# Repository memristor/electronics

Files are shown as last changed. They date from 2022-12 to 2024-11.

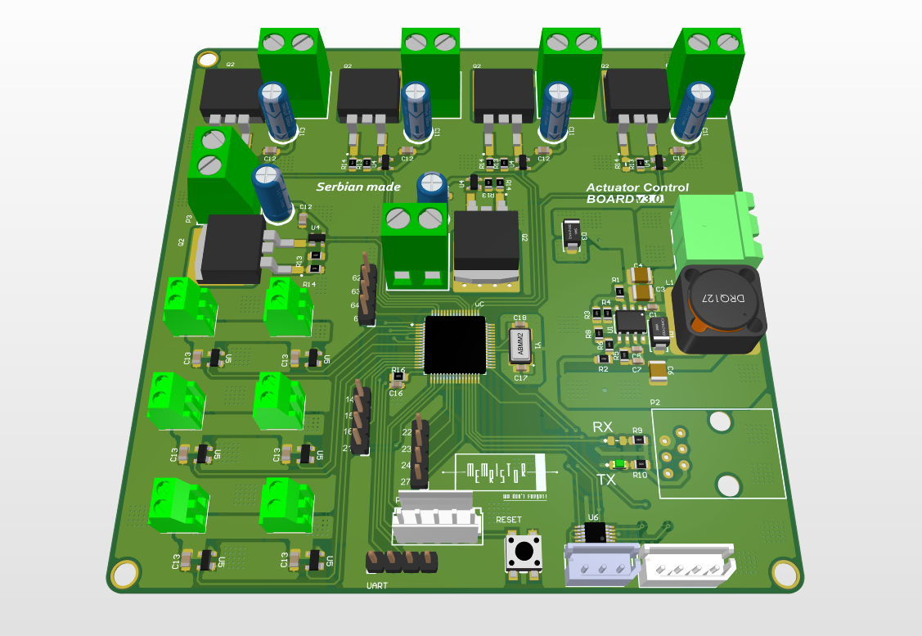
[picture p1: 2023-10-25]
actuator_board/PCB_3D.png

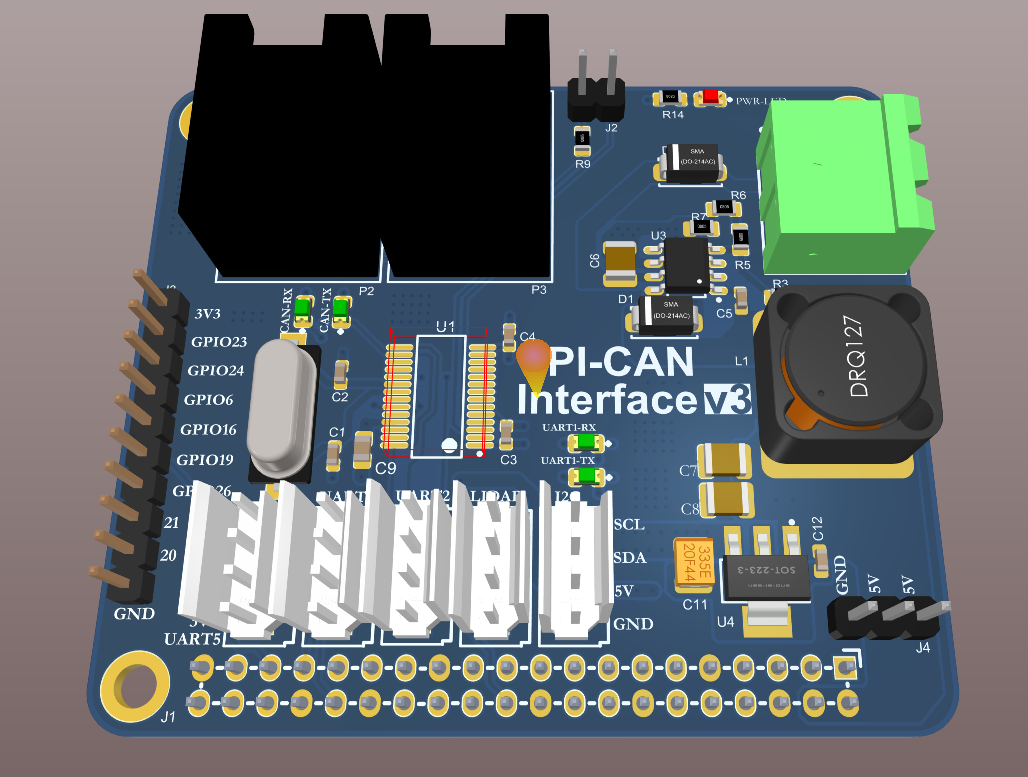
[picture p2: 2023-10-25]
pi_can_board/PCB_3D.png

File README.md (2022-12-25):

# electronics
PCBs in our Robots

Here is how we design our folder structure:

`project_name/`\
|&nbsp;&nbsp;&nbsp;&nbsp;`output_job/`\
|&nbsp;&nbsp;&nbsp;&nbsp;`pcb/`\
|&nbsp;&nbsp;&nbsp;&nbsp;`schematic/`\
|&nbsp;&nbsp;&nbsp;&nbsp;`project_name.PrjPcb`
  
Everything should be snake_case.

Gitignore considerations:\
https://electronics.stackexchange.com/questions/159220/which-files-to-version-control-for-an-altium-pcb-project
https://www.allspice.io/post/git-for-altium

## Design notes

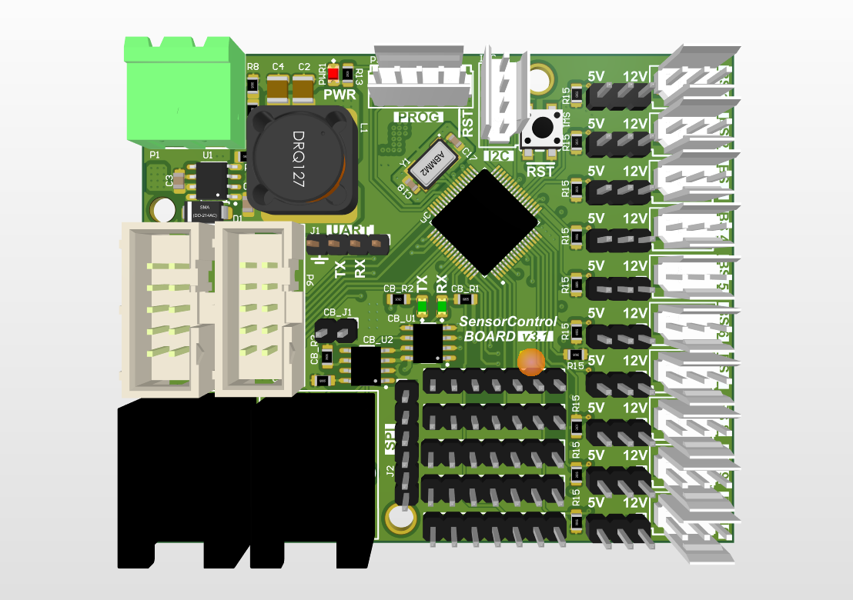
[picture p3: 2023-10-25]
sensor_board/PCB_3D.png

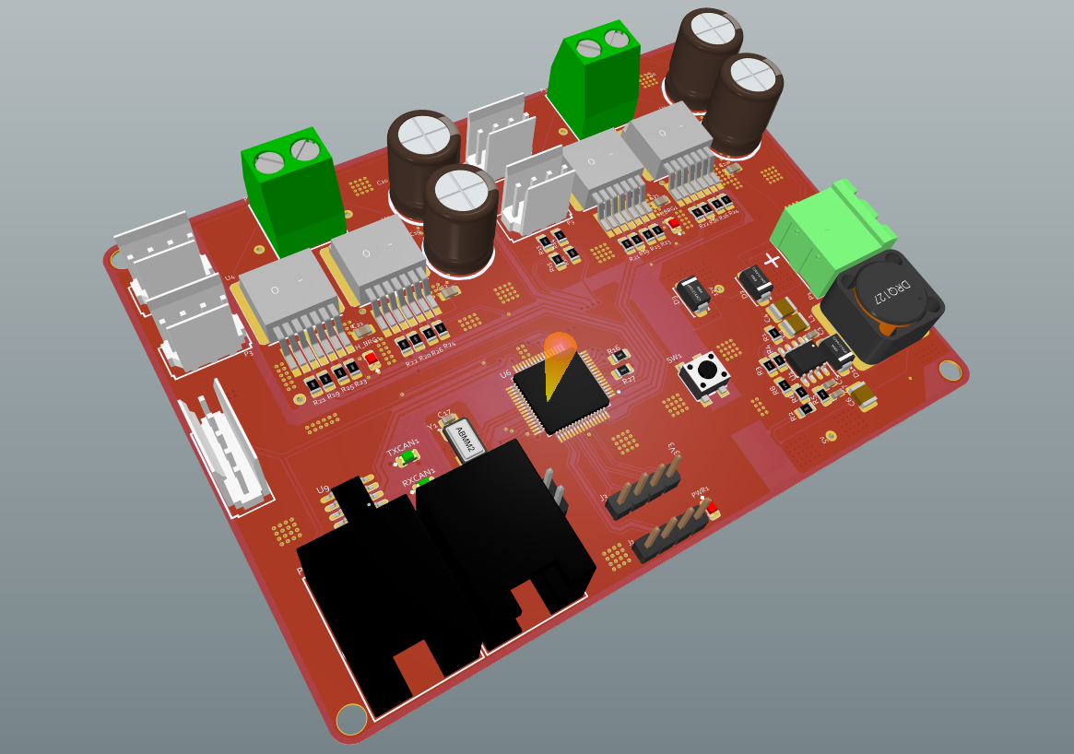
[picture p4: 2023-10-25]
motion_board/PCB_3D.png

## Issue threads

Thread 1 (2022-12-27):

Pi CAN board v3 review

VladimirVincan, 2022-12-27:
Referenca za Raspberry Pi 4: [datasheet](https://datasheets.raspberrypi.com/rpi4/raspberry-pi-4-datasheet.pdf)
Referenca za MCP251863: [datasheet](https://ww1.microchip.com/downloads/aemDocuments/documents/APID/ProductDocuments/DataSheets/MCP251863-Data-Sheet-DS20006624A.pdf)
Referenca za TPS5430: [datasheet](https://www.ti.com/lit/ds/symlink/tps5430.pdf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)

**Analiza Raspberry pinout-a:**
Potencijalno si mogao ukloniti LM2937-5, ako dovedeš Rasberiju 5 V, pretpostavljam da će vratiti 3.3 V.
Zašto nisi povezao sve GPIO pinove sa Rasberija na prilagodnu? Mislim na pinove 11, 12, 13, 15 i 26.
- pinovi 8 i 10 su jasni, RXD i TXD
- pinovi 3 i 5 su jasni, I2C
- pinovi 19, 21 i 23 su jasni, SPI
- koliko sam shvatio, pin 24 je SPI Chip Select 0 pin, i pošto imammo samo jednu periferiju, CS1 nam ne treba.
- pinovi 27 i 28 su I2C interfejs za EEPROM. Piše u datasheet-u: _DO NOT USE these pins for anything other than attaching an I2C ID EEPROM. Leave unconnected if ID EEPROM not required._ Da li tu može biti problema?
- pinovi 7 i 29 imaju ALT4 funkciju UART, jasno
- pinovi 32 i 33 imaju ALT4 funkciju UART, jasno
- pin 22 je GPIO koji si povezao sa MCP251863

**Analiza MCP251863 pinouta:**
Gledam sliku FIGURE 1-2: MCP251863 INTERFACING WITH A 3.3V MICROCONTROLLER

- imaš tri kondenzatora od 0.1 uF, odlično
- sa čime je povezan CLKO? Koliko vidim ni sa čim, onda treba staviti NC?
- zašto nisi stavio otpornike i kondenzator između CANH i CANL kao na slici?

UART:

- povezao si TXD sa TXCAN i RXD sa RXCAN, odlično
- povezao si TX od Rasberija (GPIO0) sa TXCAN od mikrokontrolera, zar ne treba obratno (TX sa RX)?
- povezao si RX od Rasberija (GPIO1) sa RXCAN od mikrokontrolera, zar ne treba obratno (RX sa TX)?

SPI:

- MOSI treba da se poveže sa SDI, odlično
- MISO treba da se poveže sa SDO, odlično
- NCS je povezan, odlično
- clock je povezan, odlično
- da bismo bili u normal modu, STDBY pin mora biti na GND, odlično

Interrupti:
- INT0 reaguje ako se pojavi TX poruka
- INT1 reaguje ako se pojavi RX poruka
- INT reaguje ako se pojavi bilo koja poruka.
- Da li nam je potreban interrupt uopšte? Da li da povežemo sva tri interrupta kao što je predloženo? Svi su aktivni na nuli.

Napajanje:
- The VCC of the CAN FD transceiver is connected to 5V - jasno.
- VDD: 2.7V to 5.5V. Pretpostavljam da si odabrao 3.3 V jer GPIO radi na 3.3 V. Koliko vidim sa šematika, CAN radi na istom naponu.

Oscilator:
-  It is recommended by the CAN FD community to use either a 40 or 20 MHz SYSCLK. Može se frekvencija podeliti sa dva unutar mikrokontrolera. Zašto si odabrao 20 MHz, a ne 40?
- Takođe, kako si odabrao kapacitivnost kondenzatora?

**Analiza za LED panel 16x2**
Koliko sam video sa [ovog ](https://www.electroniclinic.com/raspberry-pi-16x2-lcd-i2c-interfacing-and-python-programming/)sajta, redosled pinova je dobar.

**Analiza za TPS5430**
- za otpornost od 3.24kOhm-a, morate proveriti kolika je tolerancija za otpornost kod dobavljača. Ako koristite standardnu E12 seriju otpornika, onda je greška 10%, što može uticati na rezultujući napon. Kako biste to rešili?
- kapacitivnost treba da bude 220uF, a kod vas je 200uF. Već E3 serija nudi 220uF, zašto to niste stavili?
- ENA: On/off control. Below 0.5 V, the device stops switching. Float the pin to enable. Pretpostavljam da je to dobro.

**PCB dizajn**
- Moja navika je da svi GND pad-ovi budu kockasti, a ostali zaobljeni. Da li to ima smisla tako napraviti? Po meni to olakšava debagovanje i snalaženje na pločici.
- Staviti logo fakulteta, univerziteta i našeg tima?

Ammy076, 2023-01-04:
working well

angstrem98, 2023-01-05:
> Potencijalno si mogao ukloniti LM2937-5, ako dovedeš Rasberiju 5 V, pretpostavljam da će vratiti 3.3 V.

Da, vratiće. Mislim da je to odrađeno još ranije tako da se ne bi opterećivao regulator na samom raspberry-ju.

> Zašto nisi povezao sve GPIO pinove sa Rasberija na prilagodnu? Mislim na pinove 11, 12, 13, 15 i 26.

Zašto je to potrebno? Mislim ni da nema mesta na ploči.

> pinovi 27 i 28 su I2C interfejs za EEPROM. Piše u datasheet-u: DO NOT USE these pins for anything other than attaching an I2C ID EEPROM. Leave unconnected if ID EEPROM not required. Da li tu može biti problema?

Ovo si dobro primetio, promaklo mi je, ranije tu nije nista povezivano. Provericu sa Aleksandrom.

> sa čime je povezan CLKO? Koliko vidim ni sa čim, onda treba staviti NC?

Mislim da treba NC.

> zašto nisi stavio otpornike i kondenzator između CANH i CANL kao na slici?

To o čemu govoriš jeste terminacija "split termination". Mi koristimo standardnu terminaciju sa jednim otpornikom 120R.

> povezao si TX od Rasberija (GPIO0) sa TXCAN od mikrokontrolera, zar ne treba obratno (TX sa RX)?
> povezao si RX od Rasberija (GPIO1) sa RXCAN od mikrokontrolera, zar ne treba obratno (RX sa TX)?

Ovo mi nije najjasnije šta tačno misliš, ali sam primetio da je na prvi konektor za aurt dovođeno rxcan i txcan. Prosledio sam Aleksandru da ispravi.

> Da li nam je potreban interrupt uopšte? Da li da povežemo sva tri interrupta kao što je predloženo? Svi su aktivni na nuli.

Potreban je interapt i INT pin je povezan. Tako radi drajver.

> It is recommended by the CAN FD community to use either a 40 or 20 MHz SYSCLK. Može se frekvencija podeliti sa dva unutar mikrokontrolera. Zašto si odabrao 20 MHz, a ne 40?
> Takođe, kako si odabrao kapacitivnost kondenzatora?

Postoji Family Reference Manual za taj kontroler. Ali možeš samo otvoriti šemu Mikroelektronikine Click pločice i dobiti već proverenu kombinaciju kristala i kondenzatora ;)

> za otpornost od 3.24kOhm-a, morate proveriti kolika je tolerancija za otpornost kod dobavljača. Ako koristite standardnu E12 seriju otpornika, onda je greška 10%, što može uticati na rezultujući napon. Kako biste to rešili?

3k24 se uopšte ne koristi, to ti je samo u datasheet-u. Odabrao sam otpornike koji su lakše nabavljivi. A većina se sad standardno isporučuje sa tolerancijom od 1% tako da nema problema.

> kapacitivnost treba da bude 220uF, a kod vas je 200uF. Već E3 serija nudi 220uF, zašto to niste stavili?

200 uF radi ok, provereno u TI simulatoru i na ploči. Fora je što je potreban izlazni kondenzator sa veoma malom ESR, čak ni tantal ne zadovoljava već treba keramika (ili neki skup specijalni kondenzator). Vezivanje paralelno 2x100 uF keramičkih jeste jeftino i nabavljivo rešenje.

> Moja navika je da svi GND pad-ovi budu kockasti, a ostali zaobljeni. Da li to ima smisla tako napraviti? Po meni to olakšava debagovanje i snalaženje na pločici.

Možda bi moglo, vidi sa Aleksandrom. Meni je svejedno.

> Staviti logo fakulteta, univerziteta i našeg tima?

Vidi sa ostalima, ovo je nezavisno razvijano, možda ne treba?

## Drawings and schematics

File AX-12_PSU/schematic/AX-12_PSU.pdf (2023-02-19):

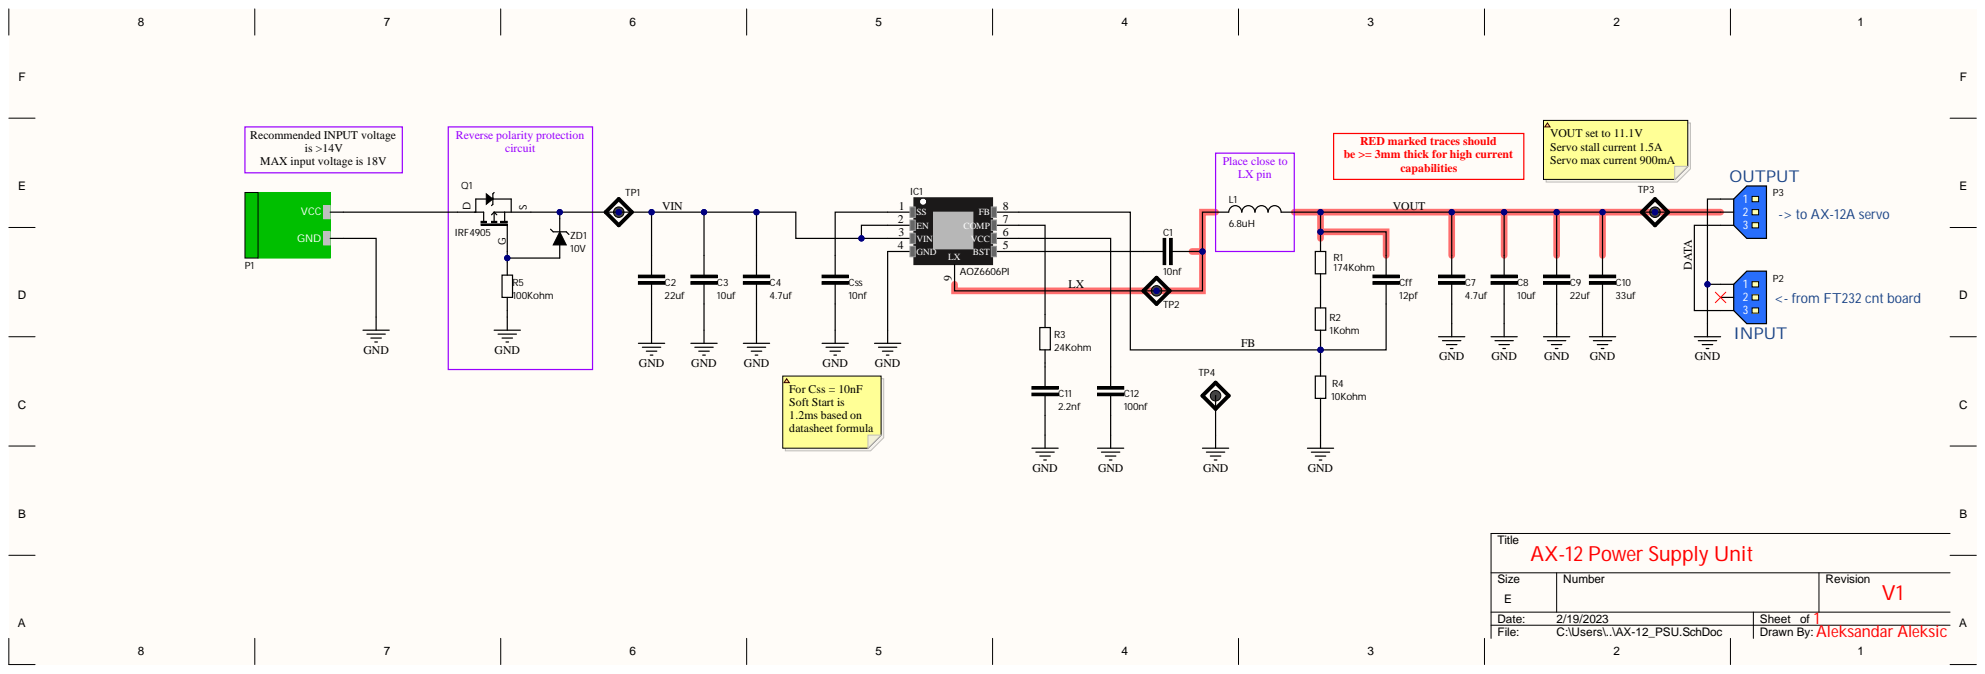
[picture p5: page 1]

Soft Start is 1.2ms based

Tit
AX-12 Power Supply Unit

Si z e E | Num b e r | Revis i o n V1

Date : 2/19/2 0 2 3 | Sheet of 1
Fil e : C:\Users\..\AX-12_PSU . S c h D o c | Drawn By : Aleksandar Aleksic

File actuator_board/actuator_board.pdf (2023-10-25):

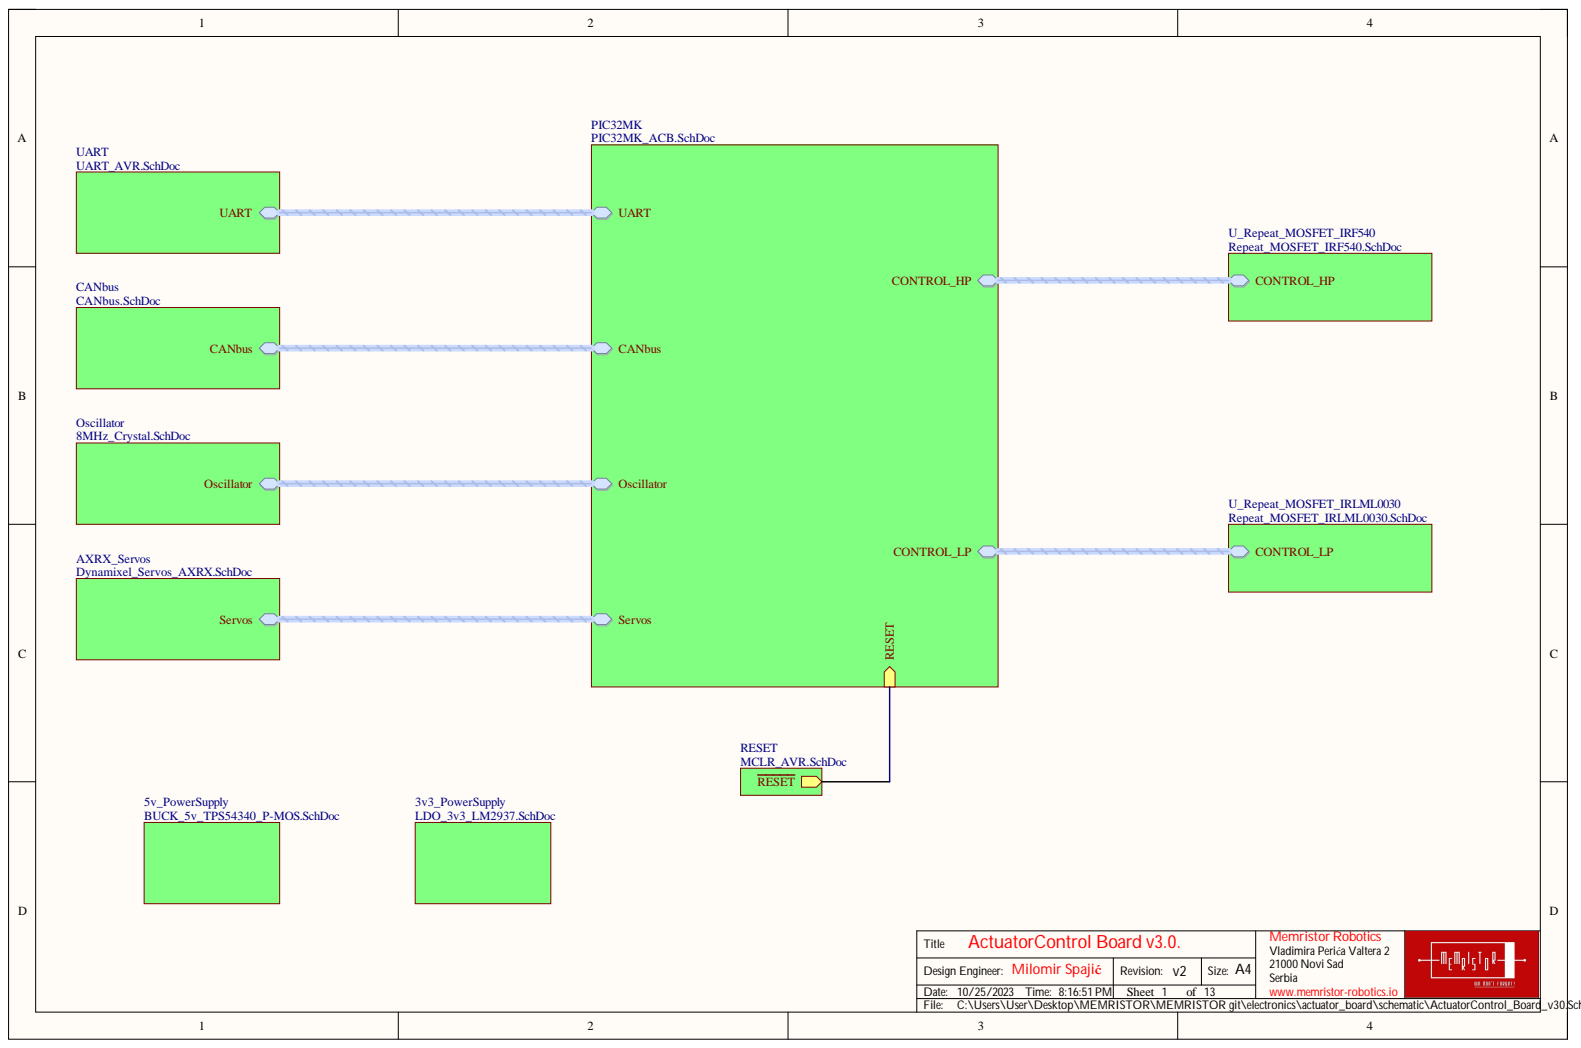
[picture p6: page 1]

ActuatorControl Board v3.0. Title | Memristor Robotics Vladimira Perića Valtera 2 21000 Novi Sad Serbia www.memristor-robotics.io

Design Engineer: Milomir Spajić | v2 Revision: | Size: A4
Date: 10/25/2023 Time: 8:16:51 PM | Sheet 1 of 13

C:\Users\User\Desktop\MEMRISTOR\MEMRISTOR git\electronics\actuator_board\schematic\ActuatorControl_Board_v30.SchDoc
File:

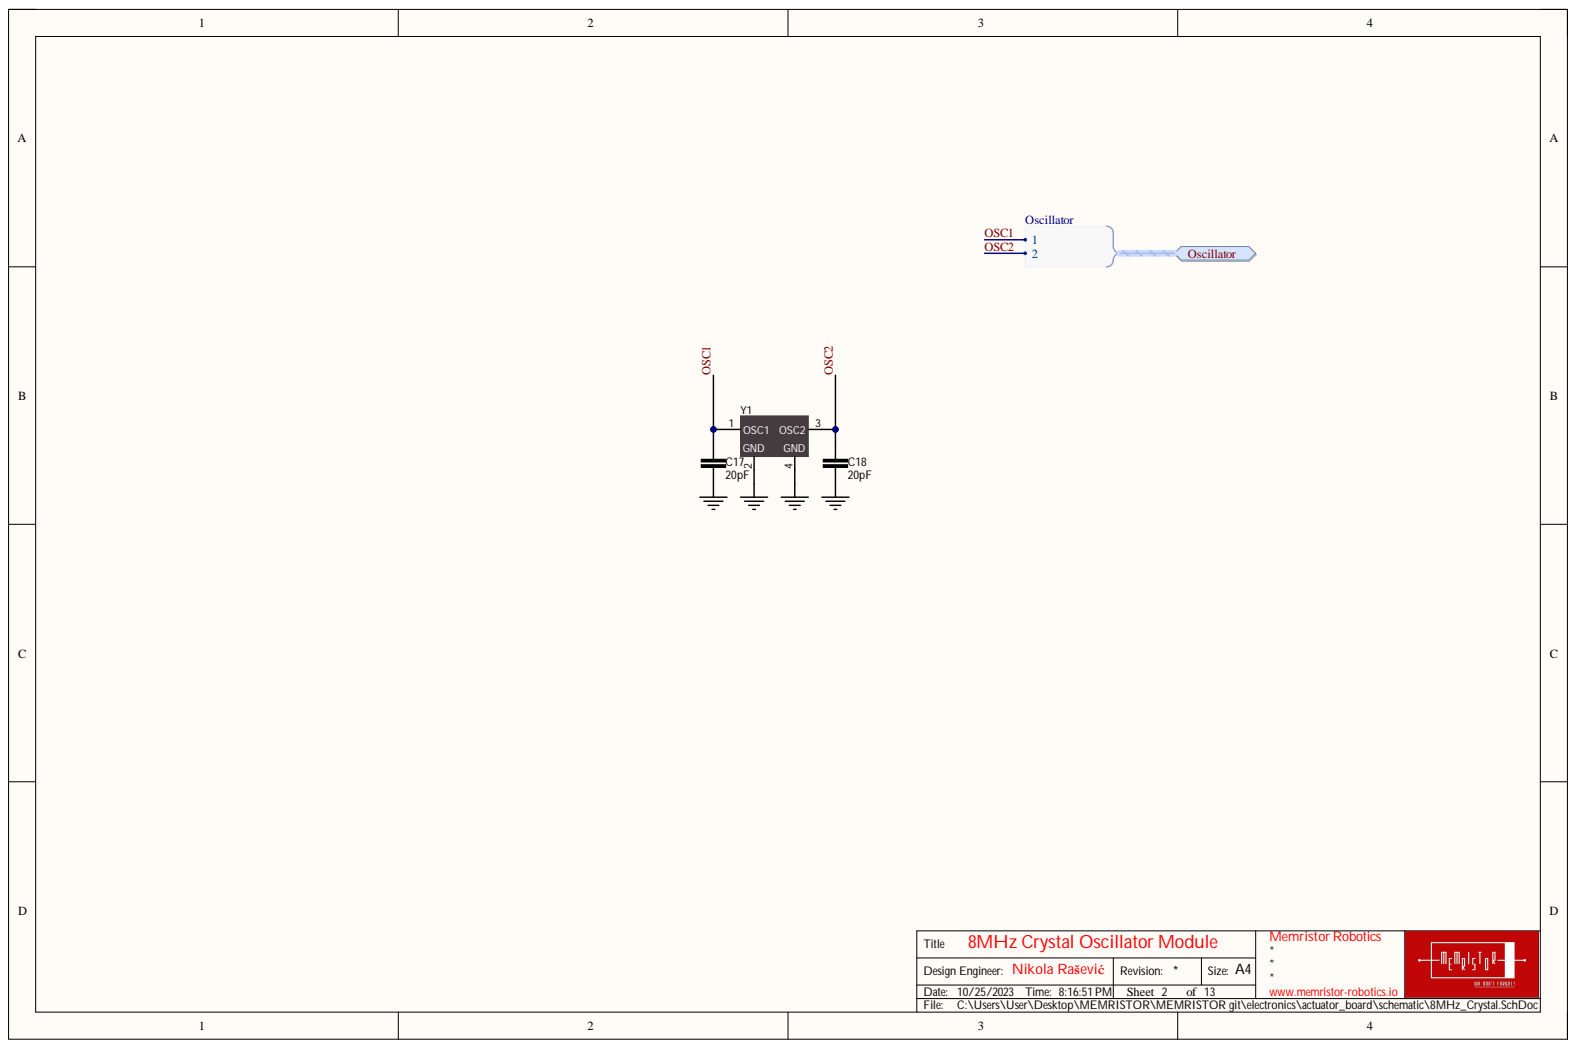
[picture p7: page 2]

8MHz Crystal Oscillator Module Title | Memristor Robotics * * * www.memristor-robotics.io

Design Engineer: Nikola Rašević | * Revision: | Size: A4
Date: 10/25/2023 Time: 8:16:51 PM | Sheet 2 of 13

C:\Users\User\Desktop\MEMRISTOR\MEMRISTOR git\electronics\actuator_board\schematic\8MHz_Crystal.SchDoc
File:

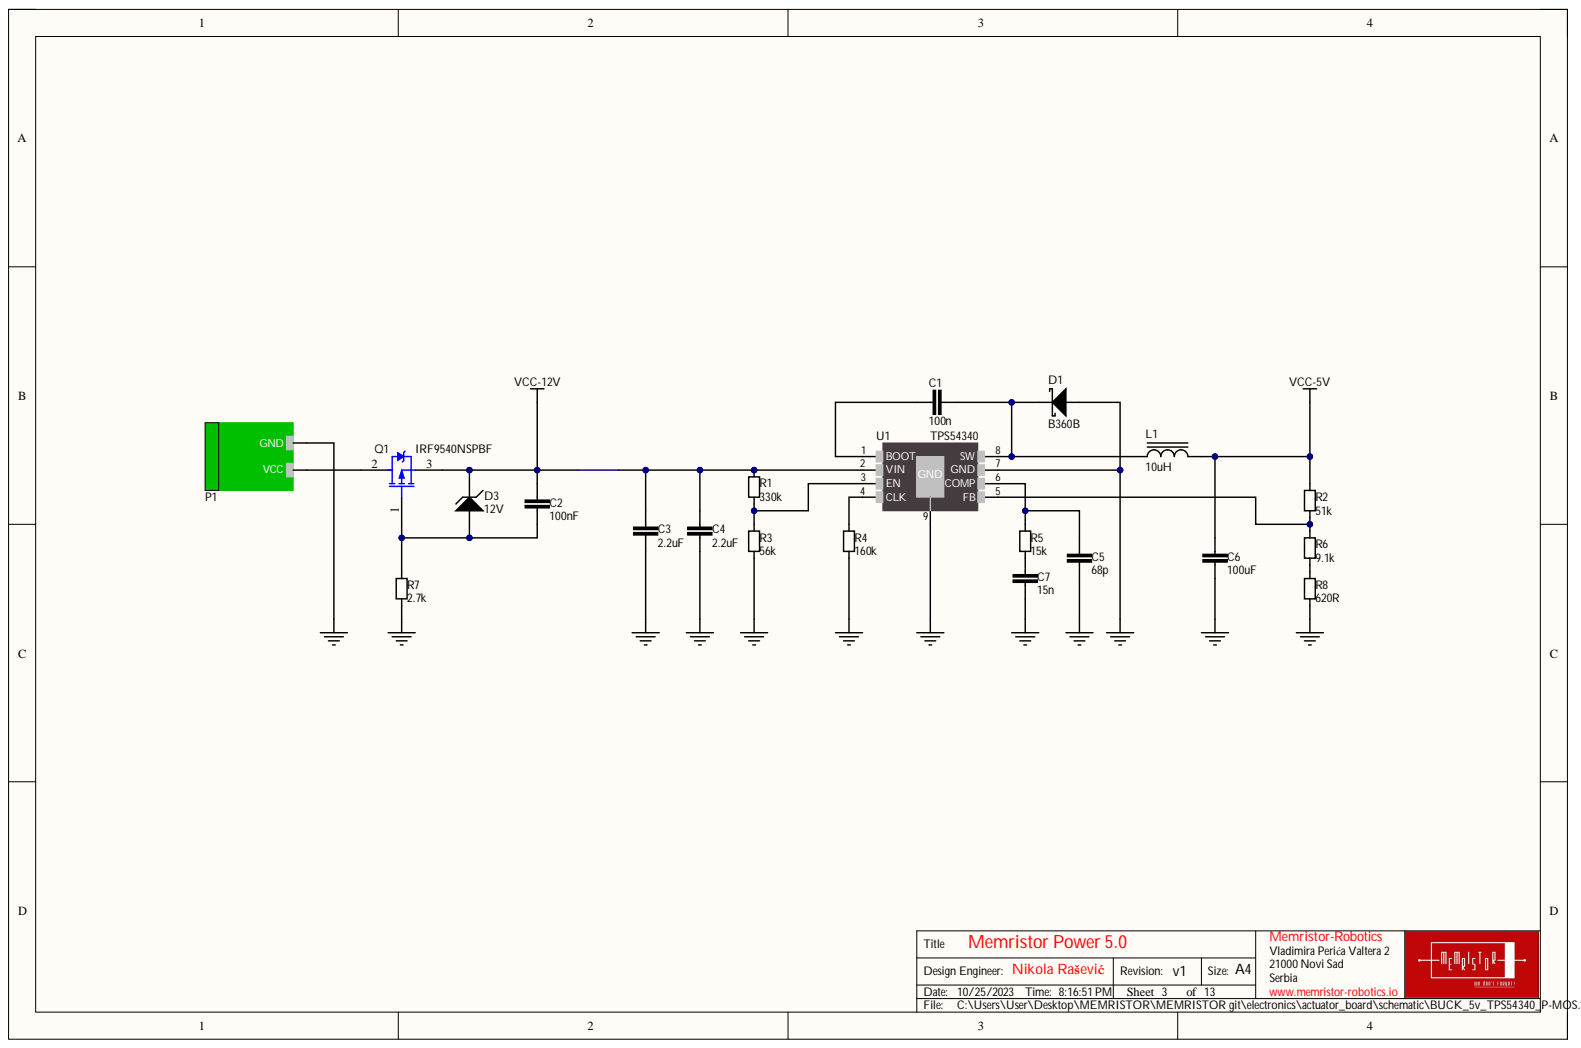
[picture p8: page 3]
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

N ikola Ra ševi ć D esign Engine e r : | v1 R ev ision : | Si A 4 z e:
Dat e : 1 0/ 2 5 / 202 3 T i m e : 8 : 1 6 : 5 1 PM | She e t 3 o f 1 3

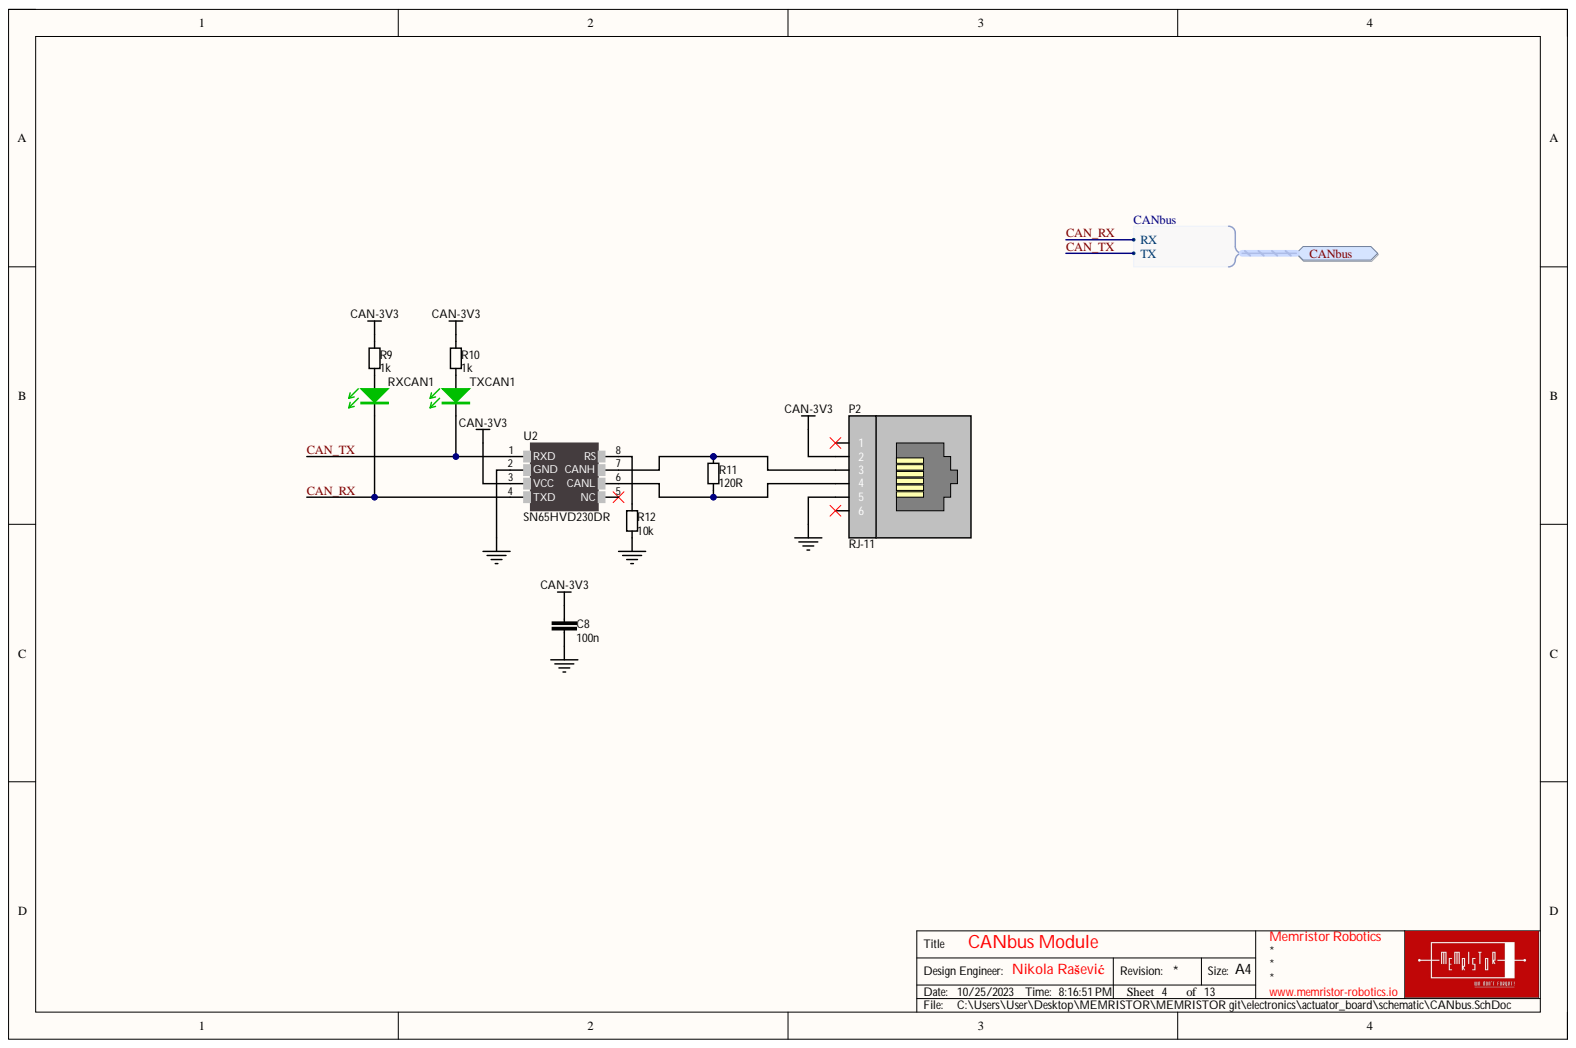
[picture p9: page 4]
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

N ikola Ra ševi ć D esign Engine e r : | * R ev ision : | Si A 4 z e:
Dat e : 1 0/ 2 5 / 202 3 T i m e : 8 : 1 6 : 5 1 PM | She e t 4 o f 1 3

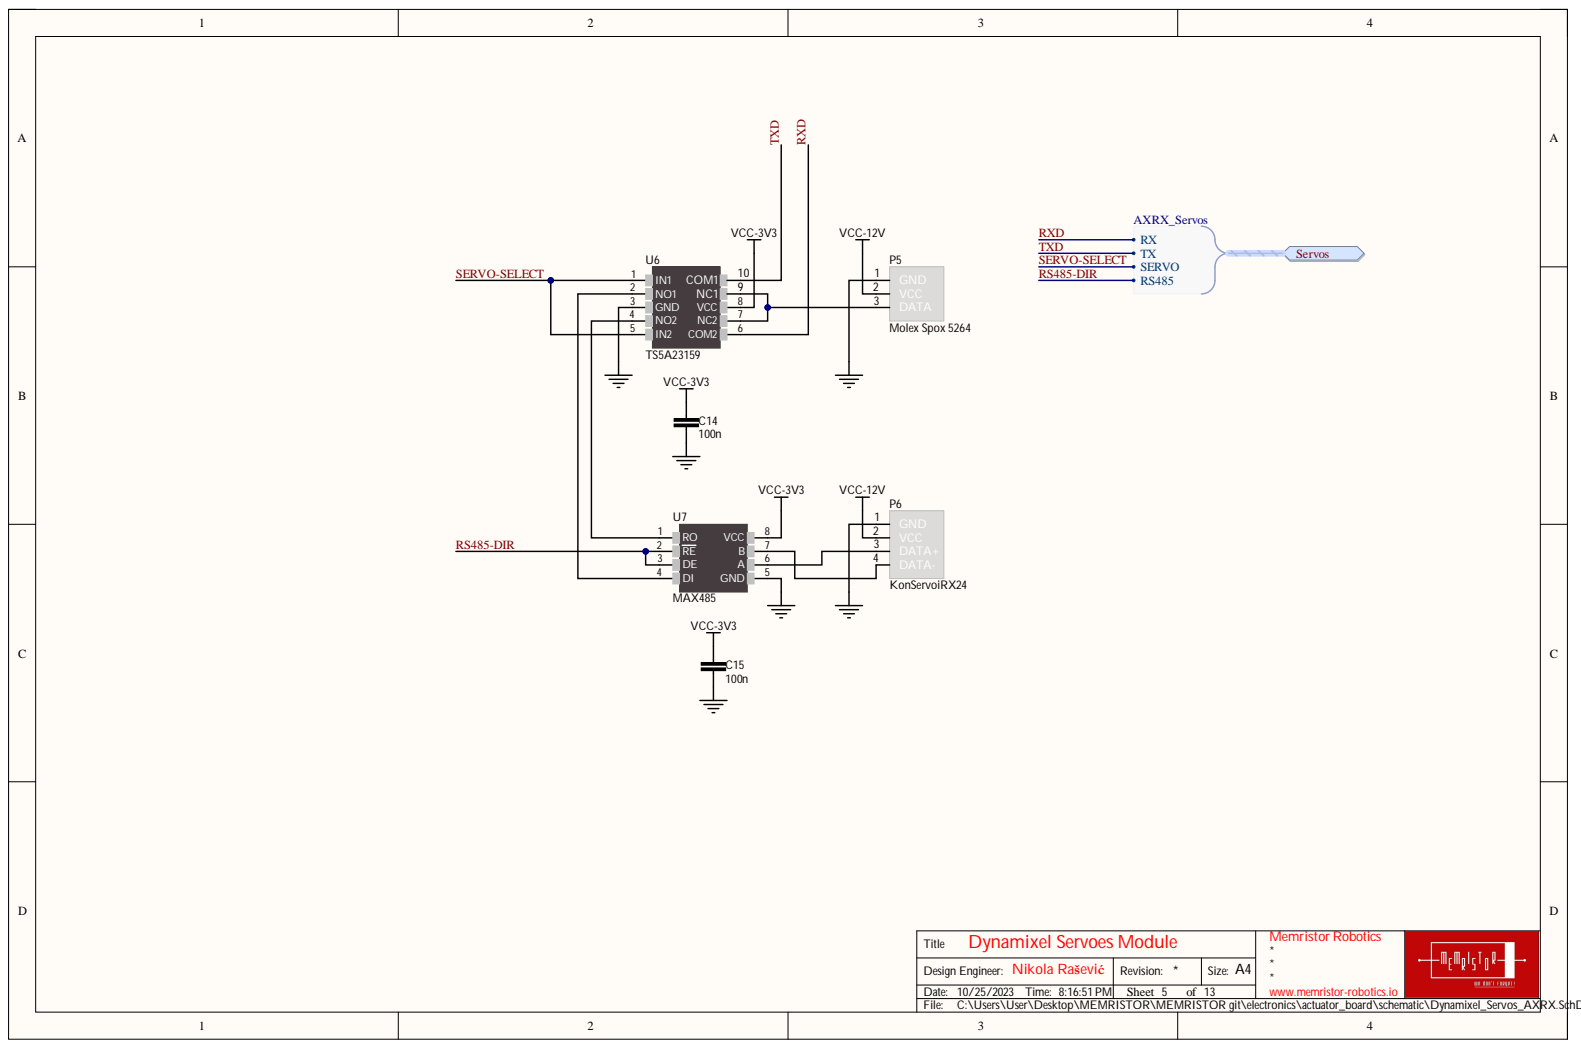
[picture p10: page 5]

Dynamixel Servoes Module Title | Memristor Robotics * * * www.memristor-robotics.io

Design Engineer: Nikola Rašević | * Revision: | Size: A4
Date: 10/25/2023 Time: 8:16:51 PM | Sheet 5 of 13

C:\Users\User\Desktop\MEMRISTOR\MEMRISTOR git\electronics\actuator_board\schematic\Dynamixel_Servos_AXRX.SchDoc
File:

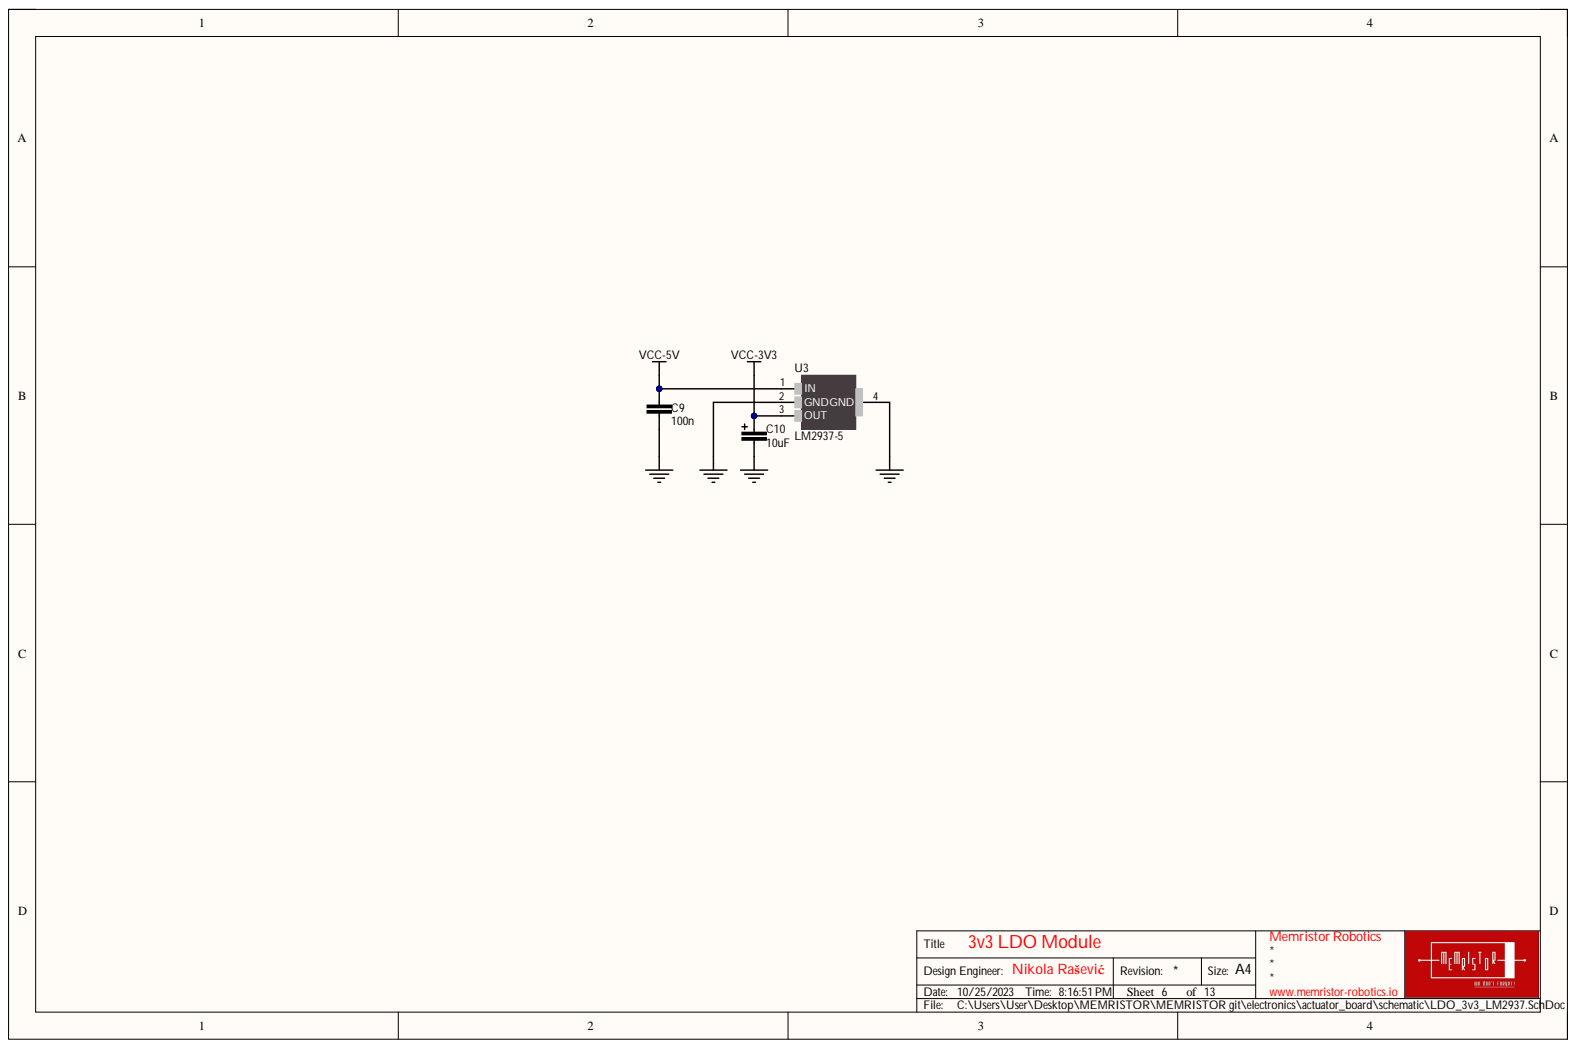
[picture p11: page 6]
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

N ikola Ra ševi ć D esign Engine e r : | * R ev ision : | Si A 4 z e:
Dat e : 1 0/ 2 5 / 202 3 T i m e : 8 : 1 6 : 5 1 PM | She e t 6 o f 1 3

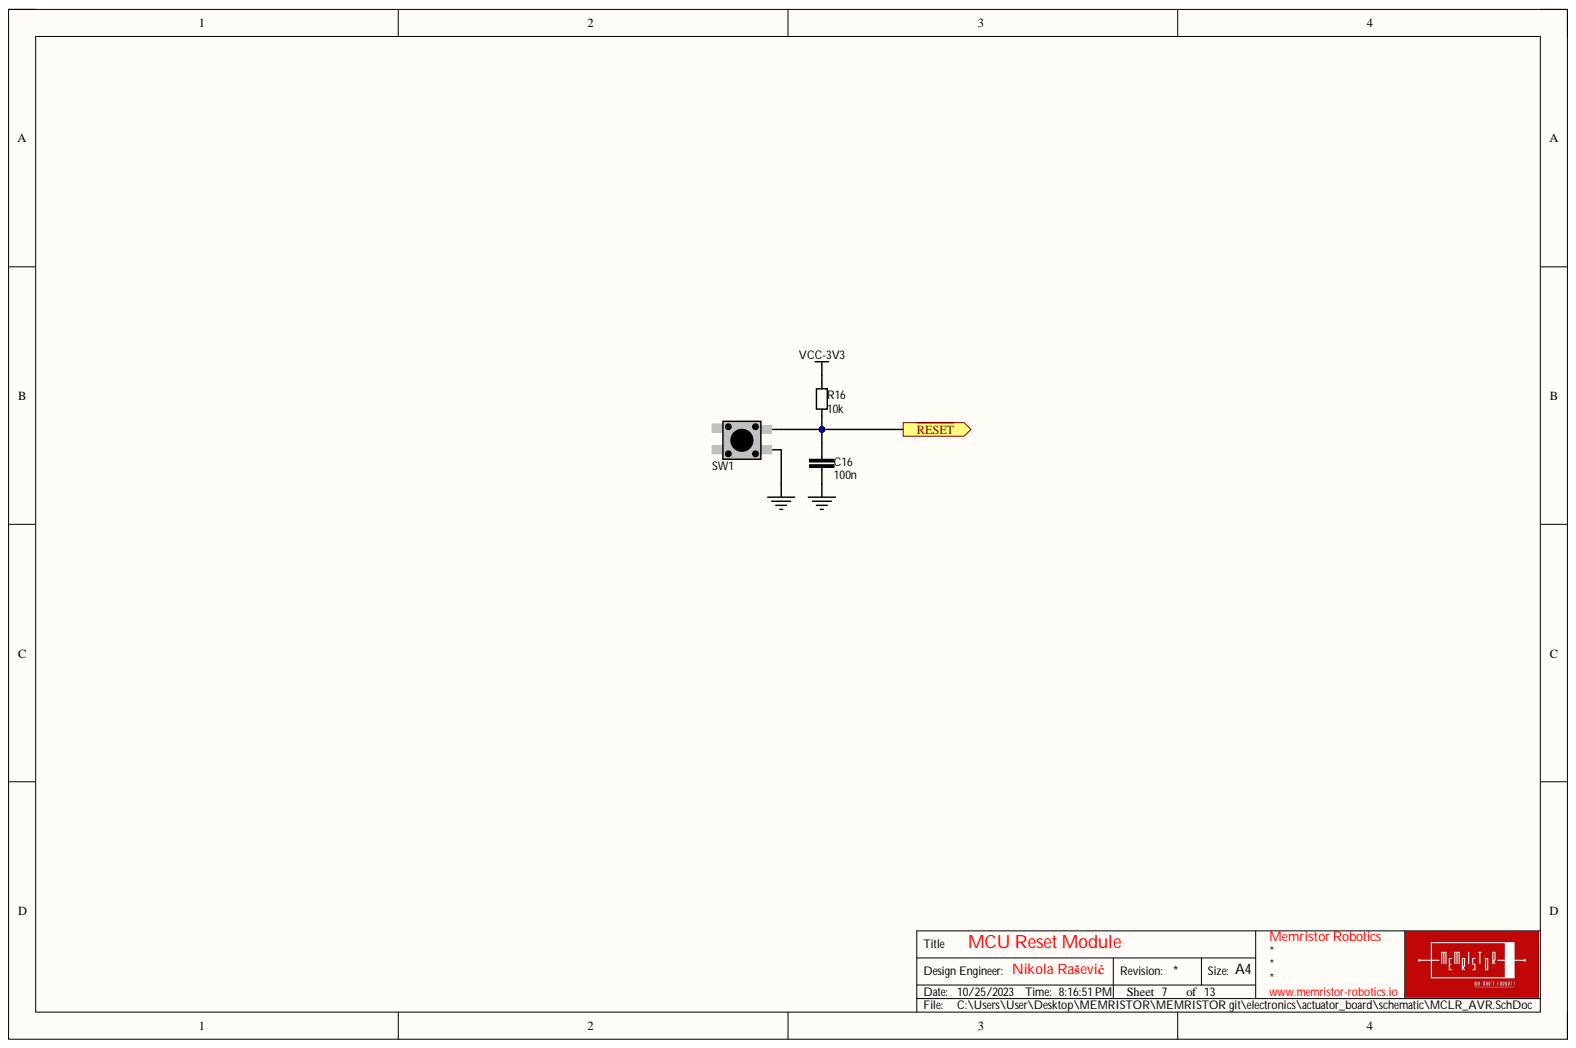
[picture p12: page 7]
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

N ikola Ra ševi ć D esign Engine e r : | * R ev ision : | Si A 4 z e:
Dat e : 1 0/ 2 5 / 202 3 T i m e : 8 : 1 6 : 5 1 PM | She e t 7 o f 1 3

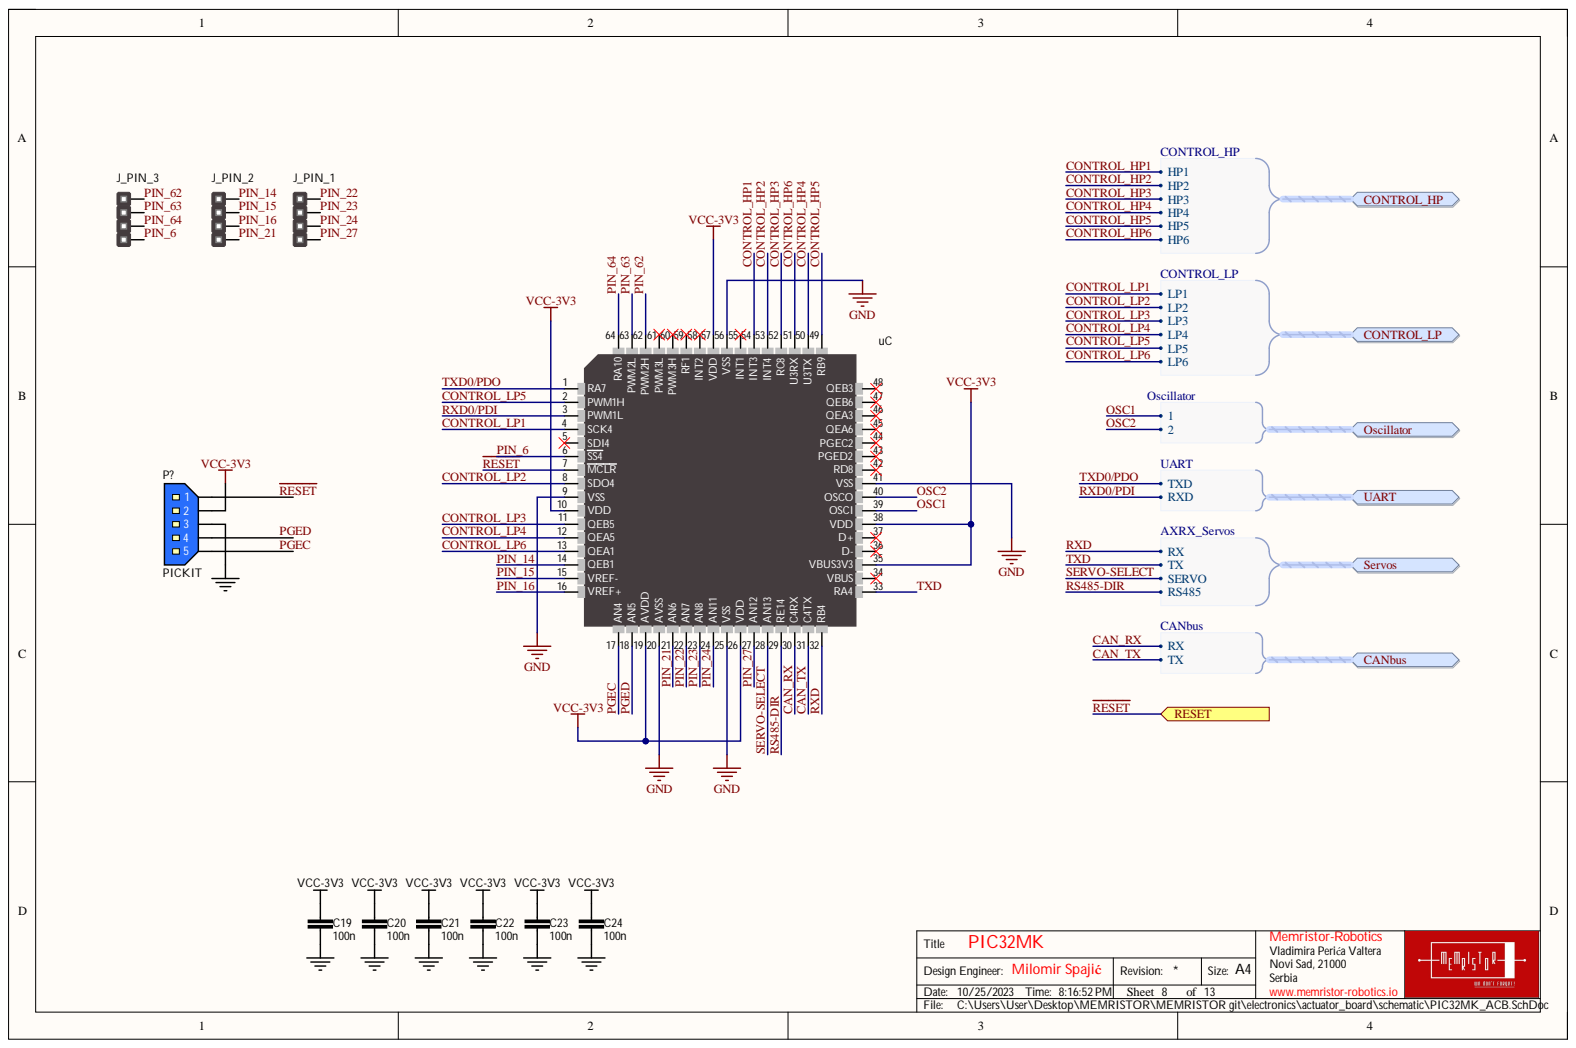
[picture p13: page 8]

VCC-3V3 VCC-3V3

PIC32MK Title | Memristor-Robotics Vladimira Perića Valtera Novi Sad, 21000 Serbia www.memristor-robotics.io

Design Engineer: Milomir Spajić | * Revision: | Size: A4
Date: 10/25/2023 Time: 8:16:52 PM | Sheet 8 of 13

C:\Users\User\Desktop\MEMRISTOR\MEMRISTOR git\electronics\actuator_board\schematic\PIC32MK_ACB.SchDoc
File:

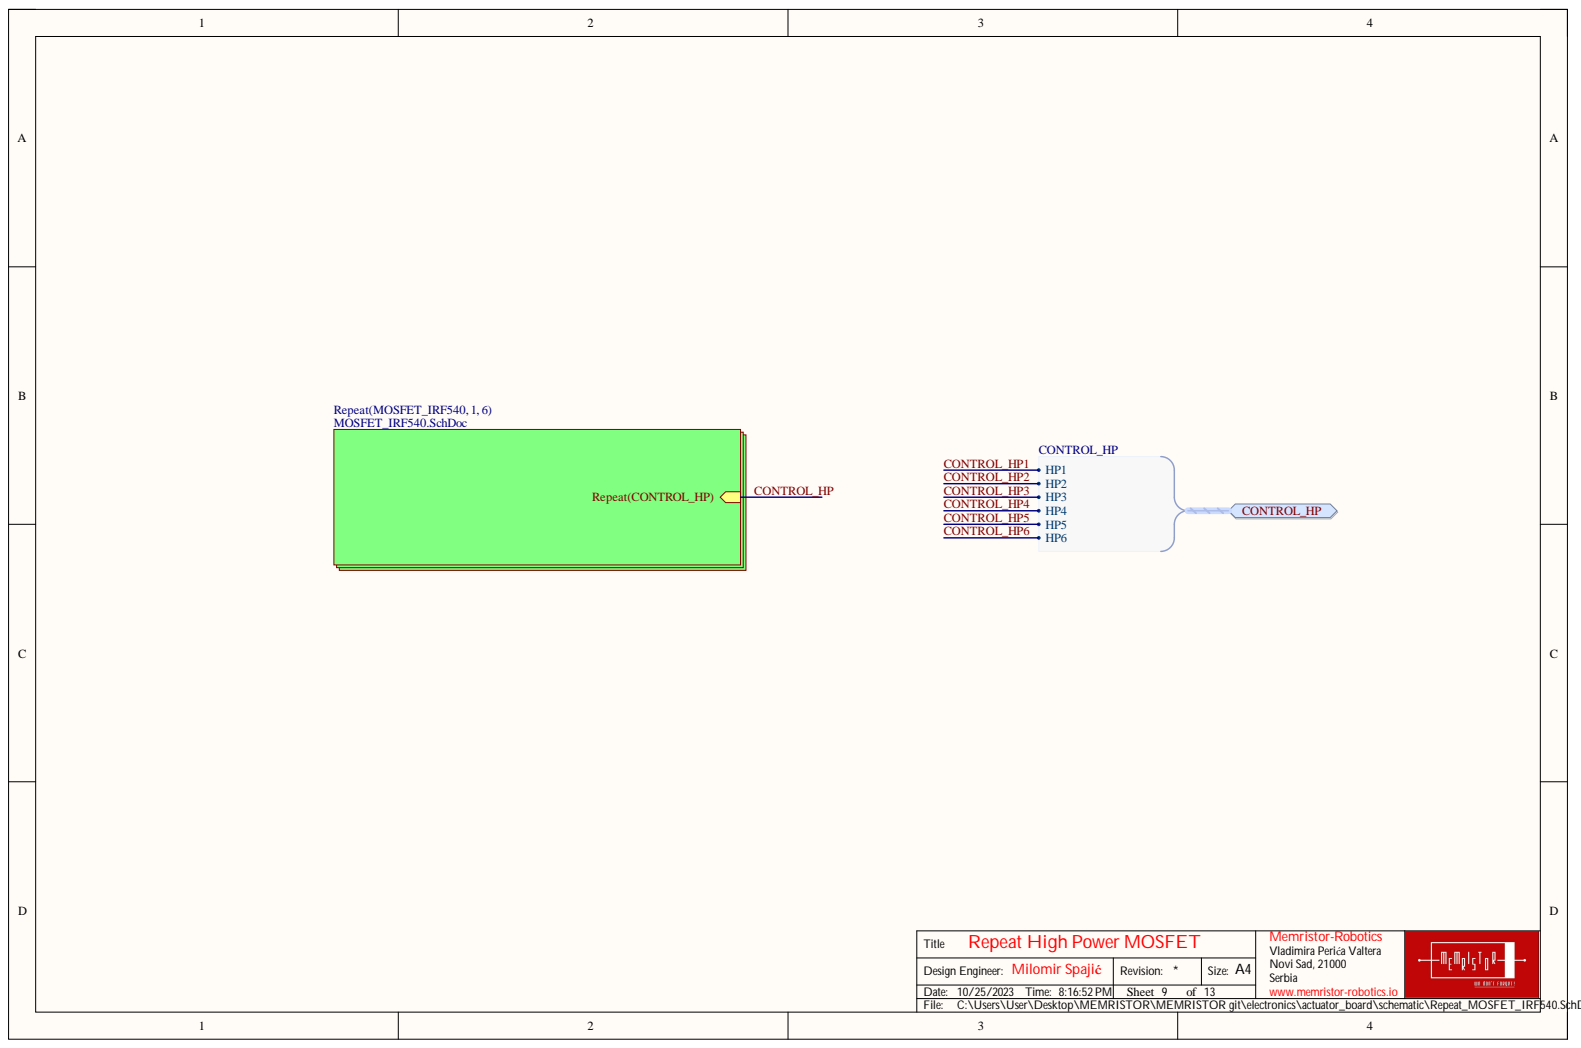
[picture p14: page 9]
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

Repeat High Power MOSFET*

M ilo m i r S p aji ć D esign Engine e r : | R ev ision : | Si A 4 z e:
Dat e : 1 0/ 2 5 / 202 3 T i m e : 8 : 1 6 : 5 2 PM | She e t 9 o f 1 3

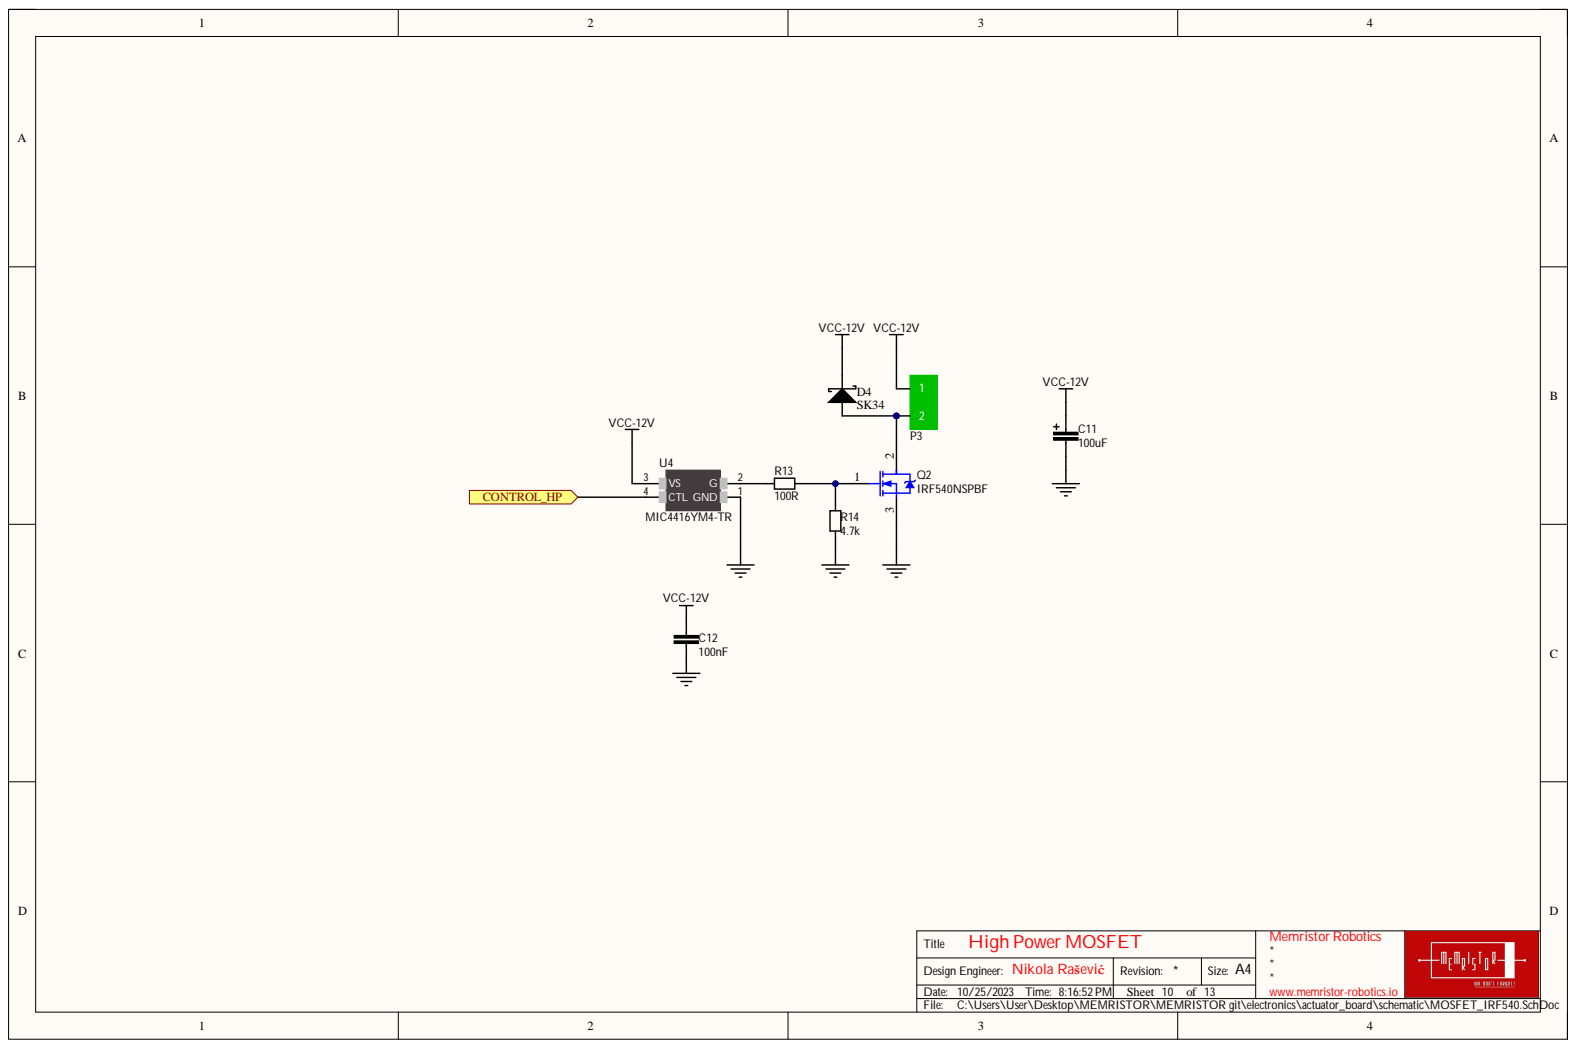
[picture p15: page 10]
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

N ikola Ra ševi ć D esign Engine e r : | * R ev ision : | Si A 4 z e:
Dat e : 1 0/ 2 5 / 202 3 T i m e : 8 : 1 6 : 5 2 PM | She e t 1 0 o f 1 3

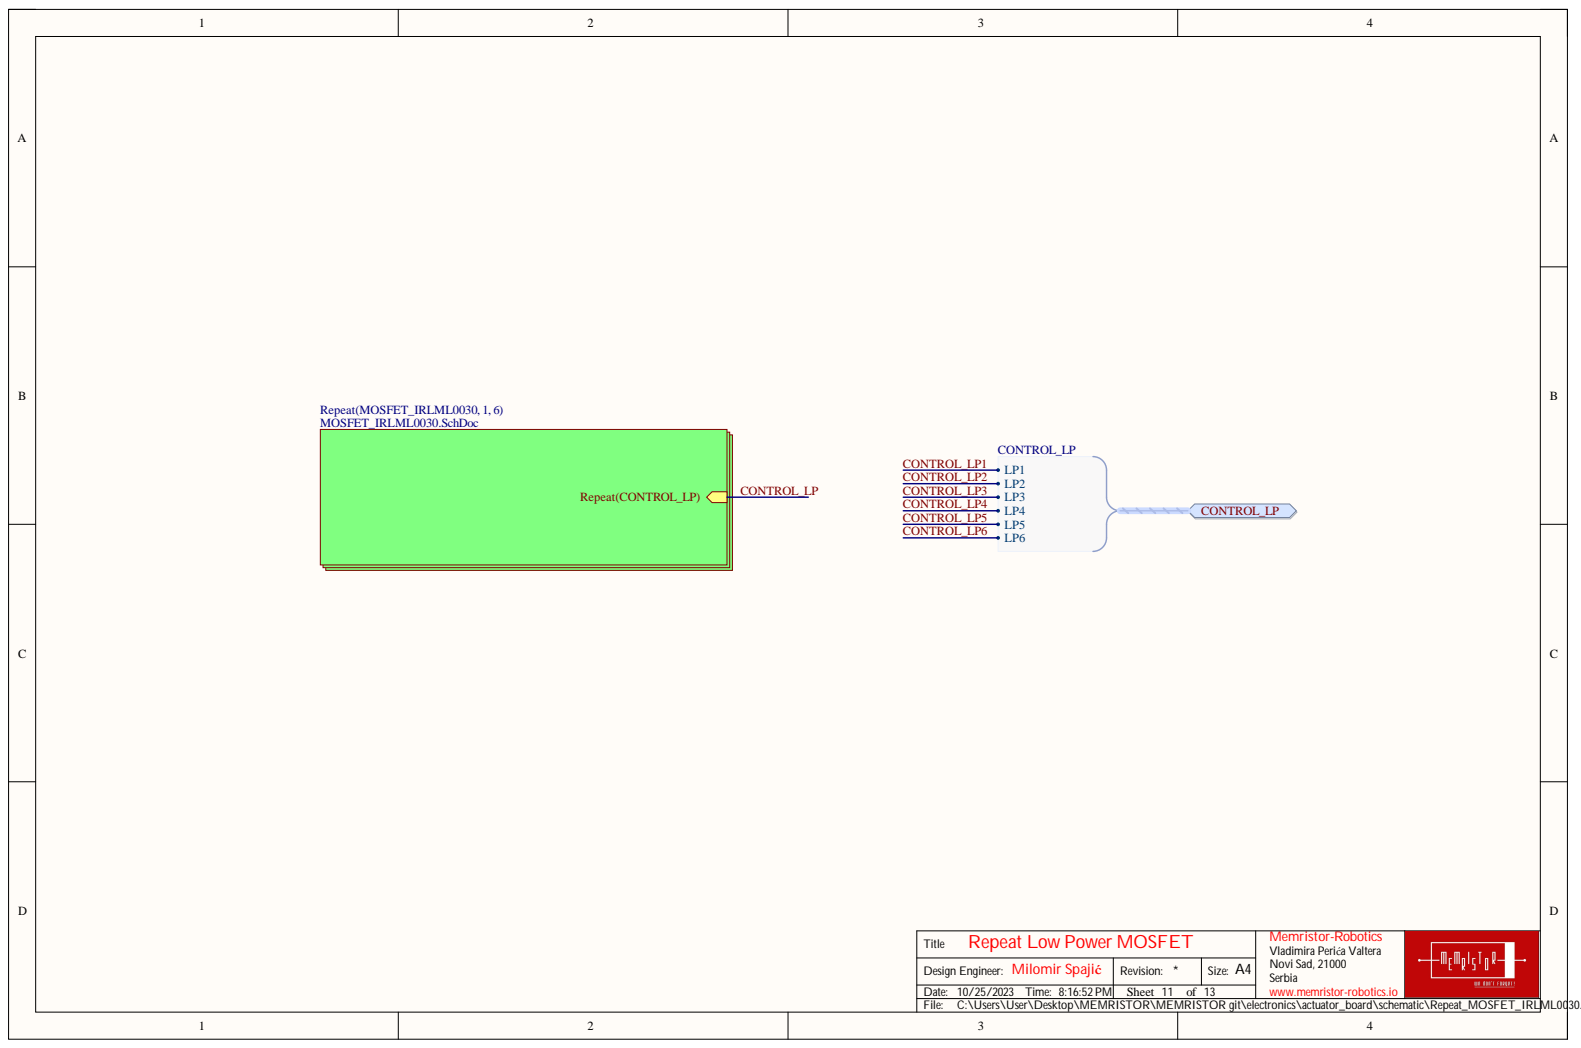
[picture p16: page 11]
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

Repeat Low Power MOSFET*

M ilo m i r S p aji ć D esign Engine e r : | R ev ision : | Si A 4 z e:
Dat e : 1 0/ 2 5 / 202 3 T i m e : 8 : 1 6 : 5 2 PM | She e t 1 1 o f 1 3

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

N ikola Ra ševi ć D esign Engine e r : | * R ev ision : | Si A 4 z e:
Dat e : 1 0/ 2 5 / 202 3 T i m e : 8 : 1 6 : 5 2 PM | She e t 1 2 o f 1 3

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

N ikola Ra ševi ć D esign Engine e r : | * R ev ision : | Si A 4 z e:
Dat e : 1 0/ 2 5 / 202 3 T i m e : 8 : 1 6 : 5 2 PM | She e t 1 3 o f 1 3


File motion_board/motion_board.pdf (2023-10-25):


Motion Driver Title | Memristor-Robotics Vladimira Perića Valtera 2 21000 Novi Sad Serbia www.memristor-robotics.io

Design Engineer: Nikola Rašević | v2 Revision: | Size: A4
Date: 10/25/2023 Time: 8:30:12 PM | Sheet 1 of 11

C:\Users\User\Desktop\MEMRISTOR\MEMRISTOR git\electronics\motion_board\schematic\Motion_Driver_v2.SchDoc
File:


Memristor Power 5.0 T i tl e | Mem risto r -R o b o ti cs Vlad i m i ra Peri ća Val tera 2 21 000 Nov i Sad Serbi a www. mem ristor-roboti cs. i o

N ikola Ra ševi ć D esign Engineer: | v1 R ev ision : | Si A 4 z e:
Date: 1 0/ 25/ 2023 T i me: 8: 30: 1 2 PM | She e t 2 o f 1 1


* Title | Memristor-Robotics Vladimira Perića Valtera Novi Sad, 21000 Serbia www.memristor-robotics.io

Design Engineer: * | * Revision: | Size: A4
Date: 10/25/2023 Time: 8:30:13 PM | Sheet 3 of 11

C:\Users\User\Desktop\MEMRISTOR\MEMRISTOR git\electronics\motion_board\schematic\Communication.SchDoc
File:


CANbus Module T i tl e | Mem risto r R o b o ti cs *** www. mem ristor-roboti cs. i o

N ikola Ra ševi ć D esign Engineer: | * R ev ision : | Si A 4 z e:
Date: 1 0/ 25/ 2023 T i me: 8: 30: 1 3 PM | She e t 4 o f 1 1


3v3 LDO Module T i tl e | Mem risto r R o b o ti cs *** www. mem ristor-roboti cs. i o

N ikola Ra ševi ć D esign Engineer: | * R ev ision : | Si A 4 z e:
Date: 1 0/ 25/ 2023 T i me: 8: 30: 1 3 PM | She e t 5 o f 1 1


* Title | Memristor-Robotics Vladimira Perića Valtera Novi Sad, 21000 Serbia www.memristor-robotics.io

Design Engineer: * | * Revision: | Size: A4
Date: 10/25/2023 Time: 8:30:13 PM | Sheet 6 of 11

C:\Users\User\Desktop\MEMRISTOR\MEMRISTOR git\electronics\motion_board\schematic\Motors-Encoders.SchDoc
File:


Encoder Title | Memristor-Robotics Vladimira Periá Valtera 2 21000 Novi Sad Serbia www.memristor-robotics.io

Design Engineer: Nikola Rašević | * Revision: | Size: A4
Date: 10/25/2023 Time: 8:30:13 PM | Sheet 7 of 11

C:\Users\User\Desktop\MEMRISTOR\MEMRISTOR git\electronics\motion_board\schematic\Encoder.SchDoc
File:


Memristor HDrive T i tl e | Mem risto r -R o b o ti cs Vlad i m i ra Peri ća Val tera 2 21 000 Nov i Sad Serbi a www. mem ristor-roboti cs. i o

N ikola Ra ševi ć D esign Engineer: | * R ev ision : | Si A 4 z e:
Date: 1 0/ 25/ 2023 T i me: 8: 30: 1 3 PM | She e t 8 o f 1 1


EMB1
EOA1
EMA1

VCC-3V3 VCC-3V3

* Title | Memristor-Robotics Vladimira Perića Valtera Novi Sad, 21000 Serbia www.memristor-robotics.io

Design Engineer: * | * Revision: | Size: A4
Date: 10/25/2023 Time: 8:30:13 PM | Sheet 9 of 11

C:\Users\User\Desktop\MEMRISTOR\MEMRISTOR git\electronics\motion_board\schematic\PIC32MK.SchDoc
File:


8MHz Crystal Oscillator Module Title | Memristor Robotics * * * www.memristor-robotics.io

Design Engineer: Nikola Rašević | * Revision: | Size: A4
Date: 10/25/2023 Time: 8:30:13 PM | Sheet 10 of 11

C:\Users\User\Desktop\MEMRISTOR\MEMRISTOR git\electronics\motion_board\schematic\8MHz_Crystal.SchDoc
File:


* T i tl e | **** www. mem ristor-roboti cs. i o

* D esign Engineer: | * R ev ision : | Si A 4 z e:
Date: 1 0/ 25/ 2023 T i me: 8: 30: 1 3 PM | She e t 1 1 o f 1 1


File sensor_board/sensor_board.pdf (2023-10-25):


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

N ikola Ra ševi æ D esign Engine e r : | * R ev ision : | Si A 4 z e:
Dat e : 1 0/ 2 5 / 202 3 T i m e : 8 : 3 8 : 3 6 PM | She e t 2 o f 1 1


riti jos jednom pinove TP

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

N ikola Ra ševi ć D esign Engine e r : | v1 R ev ision : | Si A 4 z e:
Dat e : 1 0/ 2 5 / 202 3 T i m e : 8 : 3 8 : 3 6 PM | She e t 3 o f 1 1


SDI SCK SDO SS

Siz e A4 | Numb e r | R evisio n

Da te : 10/25/20 2 3 | She et of
File : C:\Use rs\. .\Communic atio n . S c hD o c | Dr awn B y :

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

N ikola Ra ševi ć D esign Engine e r : | * R ev ision : | Si A 4 z e:
Dat e : 1 0/ 2 5 / 202 3 T i m e : 8 : 3 8 : 3 6 PM | She e t 5 o f 1 1



8MHz Crystal Oscillator Module Title | Memristor Robotics * * * www.memristor-robotics.io

Design Engineer: Nikola Rašević | * Revision: | Size: A4
Date: 10/25/2023 Time: 8:38:36 PM | Sheet 7 of 11

C:\Users\User\Desktop\MEMRISTOR\MEMRISTOR git\electronics\sensor_board\schematic\8MHz_Crystal.SchDoc
File:


* T i t l e | **** w w w . m e m r istor-robot i cs. i o

* D esign Engine e r : | * R ev ision : | Si A 4 z e:
Dat e : 1 0/ 2 5 / 202 3 T i m e : 8 : 3 8 : 3 6 PM | She e t 8 o f 1 1


Size A4 | Number | Revision

Date: 10/25/2023 | Sheet of
File: C:\Users\..\Sensors.SchDoc | Drawn By:



Siz e A4 | Numb e r | R evisio n

Da te : 10/25/20 2 3 | She et of
File : C:\Use rs\. .\P r essur e_S e n s or . S c hD o c | Dr awn B y :


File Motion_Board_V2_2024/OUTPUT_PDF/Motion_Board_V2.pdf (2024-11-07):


U_Motors-Encoders Motors-Encoders.SchDoc




LMR33630 SMPS 5V0 System Voltage Supply

work - Output set to 5V


3V3 Power[3B], CAN[2B], Communication[3B], MCLR[3B], PIC32MK[2A], Power[2B] L







Da li ici sa Male ili
Female konektorom za
motore?


Da li ici sa Male ili
Female konektorom za
motore?


GND GND





Izbacen ADUM u odnosu na
proslu verziju, jer nema
nekog znacajnog efekta.

Communication[3B], LDO[2B], MCLR[3B], PIC32MK[2A], Power[2B]

Da li je bolje da idemo sa
3pinskim JST konektorom.

Da li mora da se dovodi i 3v3
preko CAN-a?

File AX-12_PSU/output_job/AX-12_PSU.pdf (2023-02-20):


Soft Start is 1.2ms based

Tit
AX-12 Power Supply Unit

Si z e E | Num b e r | Revis i o n V1

Date : 2/20/2 0 2 3 | Sheet of 1
Fil e : C:\Users\..\AX-12_PSU . S c h D o c | Drawn By : Aleksandar Aleksic


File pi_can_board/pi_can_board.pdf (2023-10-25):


4 | C AN H
5 | | VCC-3V

PI CAN Interface PI CAN Interface T T i i tl tl e e | Mem Mem risto risto r r --R R o o b b o o ti ti cs cs Vlad Vlad i i m m i i ra Peri ra Peri ća Val ća Val tera tera Nov Nov i Sad i Sad 21 21 000 000 , , Serbi Serbi a a www. www. mem mem ristor-roboti ristor-roboti cs. cs. i i o o

A . l k sandar A l k si D D esign esign Engineer: Engineer: e e ć | v2 v2 R R ev ev ision ision : : | Si A A 4 4 Si z z e: e:
Date: Date: 1 1 0/ 0/ 25/ 25/ 2023 2023 T T i i me: me: 8: 8: 43: 43: 21 PM 21 PM | She She e e t t 1 1 o o f f 1 1


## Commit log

2022-12-25 init motion_board
    [8MHz_Crystal.SchDoc, BUCK_5v_TPS54340_P-MOS.SchDoc, CANbus.SchDoc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]
2022-12-25 init actuator_board
    [8MHz_Crystal.SchDoc, ActuatorControl_Board_v30.SchDoc, BUCK_5v_TPS54340_P-MOS.SchDoc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]
2022-12-25 init sensor_board
    [8MHz_Crystal.SchDoc, BUCK_5v_TPS54340_P-MOS.SchDoc, CANbus.SchDoc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]
2022-12-25 init pi_can_board
    [PI_CAN_Interface_v3.SchDoc, pi_can_board.PrjPcb]
2022-12-26 update sensor_board version
    [8MHz_Crystal.SchDoc, BUCK_5v_TPS5430.SchDoc, BUCK_5v_TPS54340_P-MOS.SchDoc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]
2023-02-19 Initial commit - schematic V1
    [AOZ6606PI.SchLib, AX-12_PSU.PcbDoc, AX-12_PSU.PrjPcb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]
2023-02-19 Footprints, SCH and PCB library added
    [AX-12_PSU.SchDoc]
2023-02-19 TestPoints added
    [AX-12_PSU.SchDoc]
2023-02-19 Reverse polarity protection added
    [AX-12_PSU.PcbDoc, AX-12_PSU.SchDoc]
2023-02-19 New schematic PDF output
    [AX-12_PSU.PcbDoc, AX-12_PSU.PrjPcb]
2023-02-19 PCB routed
    [AX-12_PSU.PcbDoc]
2023-02-20 PCB reorganization
    [AX-12_PSU.PcbDoc]
2023-02-20 New PDF output
    [AX-12_PSU.PcbDoc, AX-12_PSU.PrjPcb]
2023-02-24 Gerber files generated
    [AX-12_PSU.PcbDoc, AX-12_PSU.PrjPcb]
2024-07-31 Added Motion Board V2 Initial folder structure
    [5V0_SYS_SUPPLY.SchDoc, CapacitorsFootprins.PcbLib, Footprints_integrated.PcbLib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]
2024-11-07 Nekompletna Sema Kretacke Plocice
    [5V0_SYS_SUPPLY.SchDoc, CAN.SchDoc, Communication.SchDoc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]
2024-11-11 Sredjen CAN
    [5V0_SYS_SUPPLY.SchDoc, CAN.SchDoc, Communication.SchDoc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]
2024-11-20 Popravljen NC na BUCKu, napravljen Layout
    [5V0_SYS_SUPPLY.SchDoc, CAN.SchDoc, HBridge.SchDoc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]
2024-11-27 Layout pri kraju
    [5V0_SYS_SUPPLY.SchDoc, CAN.SchDoc, Crystal.SchDoc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]
2024-11-29 Rutiranje zavrseno, ostale finese
    [HBridge.SchDoc, Motion_Board_V2_PCB.PcbDoc]
2024-12-03 Rule Check
    [Motion_Board_V2_PCB.PcbDoc]
2024-12-06 Power Check
    [5V0_SYS_SUPPLY.SchDoc, CAN.SchDoc, Communication.SchDoc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]
2024-12-11 Final Check
    [MCLR.SchDoc, Motion_Board_V2_PCB.PcbDoc]
2024-12-12 Final Check V2
    [Motion_Board_V2_PCB.PcbDoc]
2024-12-14 VREF Fix
    [Motion_Board_V2_PCB.PcbDoc, PIC32MK.SchDoc]
2024-12-15 Final Touch
    [5V0_SYS_SUPPLY.SchDoc, Motion_Board_V2_PCB.PcbDoc]
2024-12-18 Final Check Done
    [HBridge.SchDoc, Motion_Board_V2_PCB.PcbDoc, REVERSE_PROTECTION.SchDoc]
2024-12-22 Vref+&- Change Fix
    [Motion_Board_V2_PCB.PcbDoc, PIC32MK.SchDoc]
2024-12-23 Taster Via Moved
    [Motion_Board_V2_PCB.PcbDoc]
2024-12-23 GND Poly Fix
    [Motion_Board_V2_PCB.PcbDoc]
2025-01-09 Gerbers Added
    [Motion_Board_V2.PrjPcb, Motion_Board_V2_PCB.PcbDoc]
2025-12-07 Napisane Greske Koje Su Uocene Posle Porudzbine
    [5V0_SYS_SUPPLY.SchDoc, Encoder.SchDoc, MotionBoard_V2.SchDoc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]
